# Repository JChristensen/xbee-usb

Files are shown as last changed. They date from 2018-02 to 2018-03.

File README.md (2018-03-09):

# XBee USB Dongle
https://github.com/JChristensen/xbee-usb  
README file  
Jack Christensen Feb-2018

## Overview
This dongle was mainly intended to connect an XBee semi-permanently to a Raspberry Pi, neatly without cables, for communication with an application program. Of course it can be used with any other computer as well. It's also useful for programming an XBee with [Digi's XCTU utility](https://www.digi.com/products/xbee-rf-solutions/xctu-software/xctu), or as a range extender in the mesh network by just plugging it into a 5V wall wart, phone charger, etc.

Via a solder jumper on the back of the board, the XBee's reset pin can be connected either to a pushbutton switch or to the CBUS3 pin on the FTDI FT231X chip. To use CBUS3 as a reset line, configure it as a GPIO pin using [the FTDI FT_PROG utility](http://www.ftdichip.com/Support/Utilities.htm#FT_PROG).

PC boards can be ordered [from OSH Park](https://www.oshpark.com/shared_projects/egIOkt1Z).  
A bill of materials is available [at Mouser Electronics](https://www.mouser.com/ProjectManager/ProjectDetail.aspx?AccessID=f236469f0d) and also in this repo.

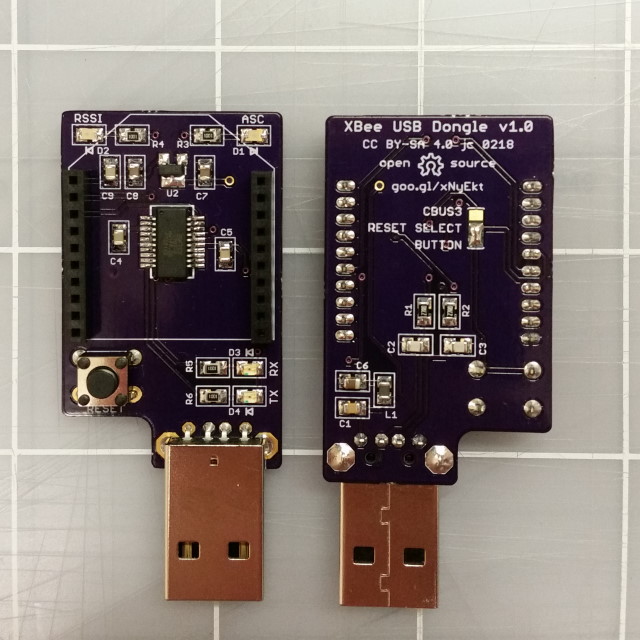
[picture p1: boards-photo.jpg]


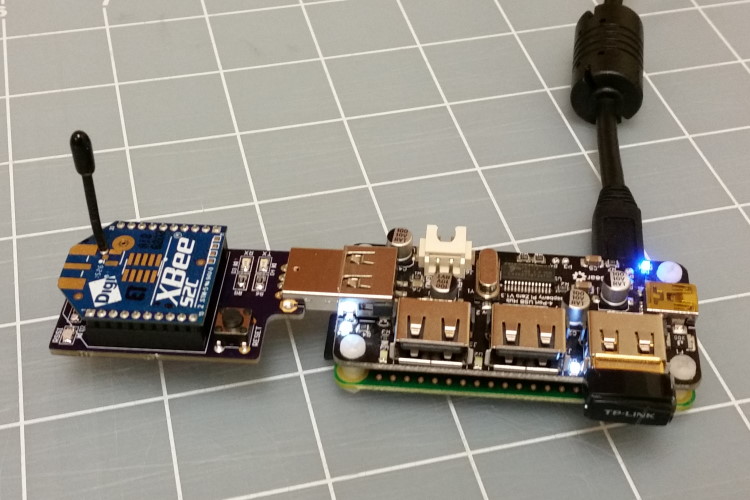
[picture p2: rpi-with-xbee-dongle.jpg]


**Raspberry Pi Zero with [Zero4U USB hub](https://www.adafruit.com/product/3298) and XBee USB Dongle.**

## CC BY-SA
"XBee USB Dongle" by Jack Christensen is licensed under [CC BY-SA 4.0](https://creativecommons.org/licenses/by-sa/4.0/).

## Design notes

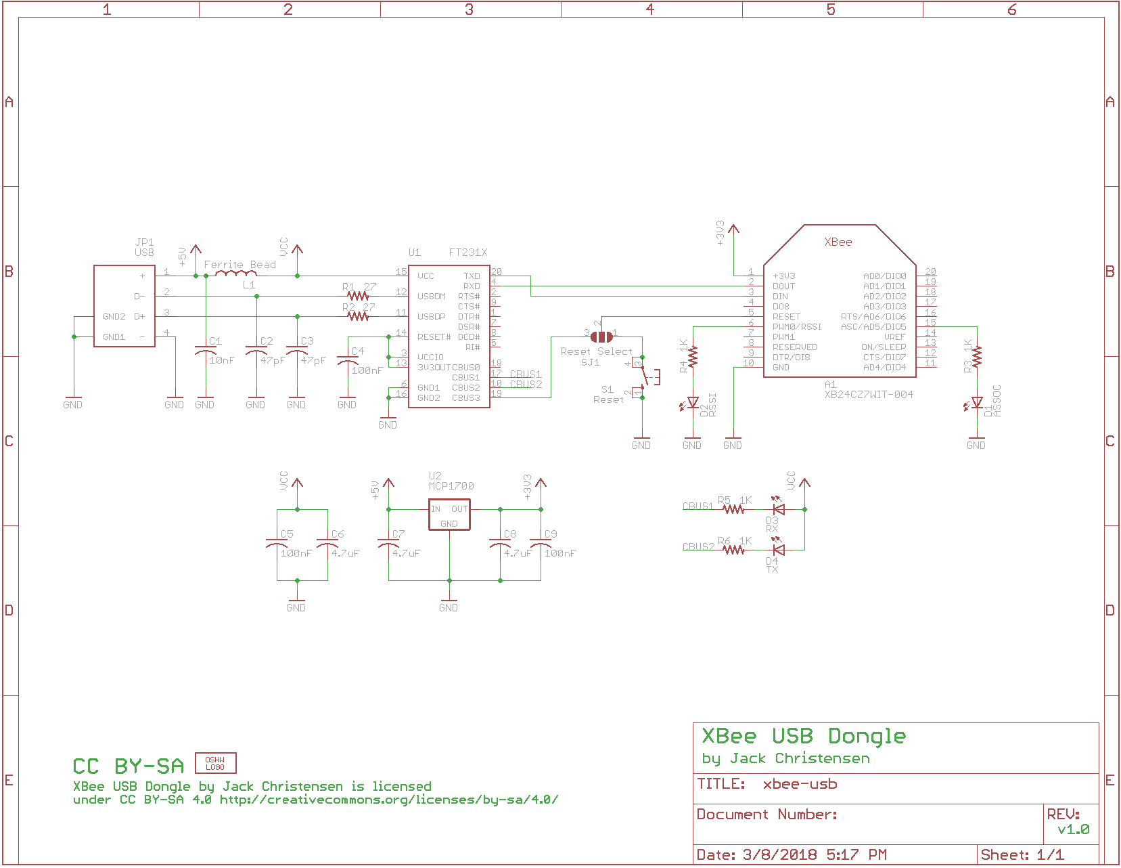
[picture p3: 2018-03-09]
schematic.png

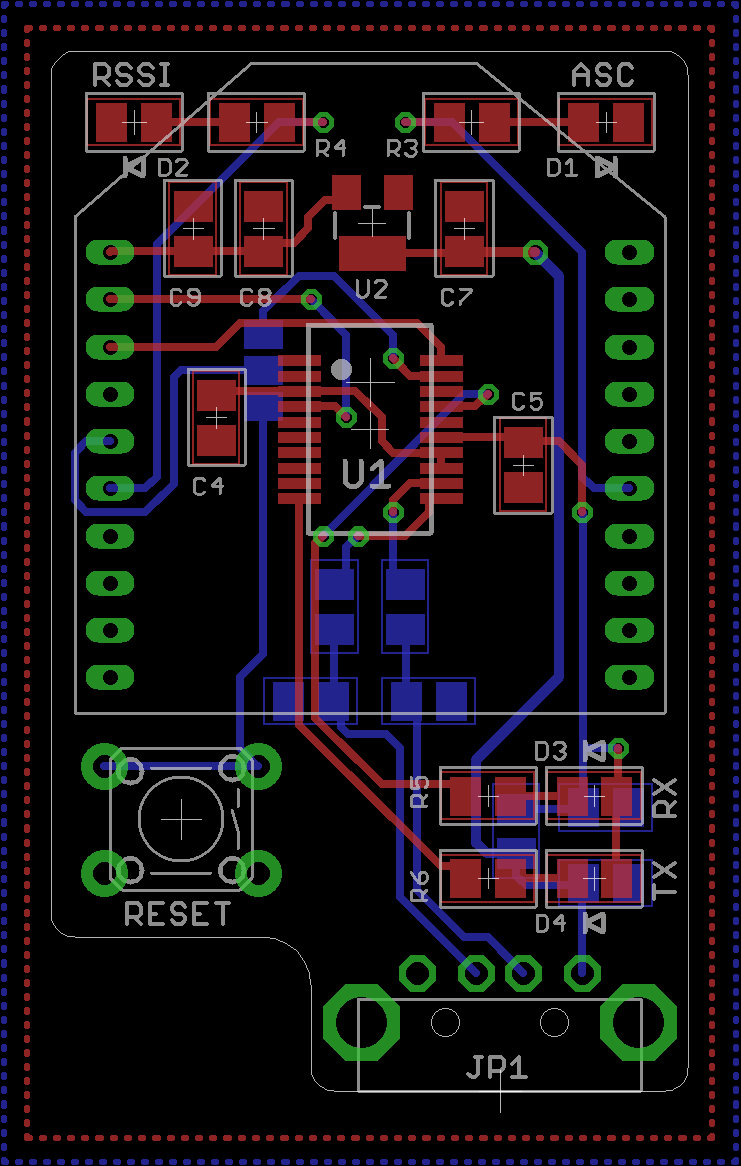
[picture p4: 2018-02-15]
board.png

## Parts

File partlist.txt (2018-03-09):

Partlist

Exported from xbee-usb.sch at 3/8/2018 5:17 PM

EAGLE Version 7.5.0 Copyright (c) 1988-2015 CadSoft

Assembly variant: 

Part     Value          Device             Package        Library  Sheet

A1       XB24CZ7WIT-004 ULINK_XBEEOVALPADS XBEE_OVAL_PADS _jc      1
C1       10nF           C-USM0805          M0805          _jc      1
C2       47pF           C-USM0805          M0805          _jc      1
C3       47pF           C-USM0805          M0805          _jc      1
C4       100nF          C-USM0805          M0805          _jc      1
C5       100nF          C-USM0805          M0805          _jc      1
C6       4.7uF          C-USM0805          M0805          _jc      1
C7       4.7uF          C-USM0805          M0805          _jc      1
C8       4.7uF          C-USM0805          M0805          _jc      1
C9       100nF          C-USM0805          M0805          _jc      1
D1       ASSOC          LEDD0805           D0805          _jc      1
D2       RSSI           LEDD0805A          D0805A         _jc      1
D3       RX             LEDD0805           D0805          _jc      1
D4       TX             LEDD0805A          D0805A         _jc      1
JP1      USB            UP2-AH-TH          UP2-AH-X-TH    _jc      1
L1       Ferrite Bead   INDUCTORM0805      M0805          _jc      1
R1       27             R-US_M0805         M0805          _jc      1
R2       27             R-US_M0805         M0805          _jc      1
R3       1K             R-US_M0805         M0805          _jc      1
R4       1K             R-US_M0805         M0805          _jc      1
R5       1K             R-US_M0805         M0805          _jc      1
R6       1K             R-US_M0805         M0805          _jc      1
S1       Reset          10-XXOCT           B3F-10XXOCT    _jc      1
SJ1      Reset Select   SJ2W               SJ_2           jumper   1
U1       FT231X         FT231XSSOP20-W     SSOP20-W       _jc      1
U2       MCP1700        MCP1700SOT23-W     SOT23-W        _jc      1

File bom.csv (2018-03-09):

XBee USB Dongle
Bill of Materials
Jack Christensen Mar-2018
https://github.com/JChristensen/xbee-usb
Part | Value | Order Qty. | Mouser # | Mfr. # | Manufacturer | Description
A1 | 2mm headers | 2 | 855-M22-7131042 | M22-7131042 | Harwin | Headers & Wire Housings 10 PIN SIL VERTICAL GOLD+TIN SOCKET
A1 | XB24CZ7WIT-004 (optional/or as desired) | 1 | 888-XB24CZ7WIT-004 | XB24CZ7WIT-004 | Digi International | Zigbee / 802.15.4 Modules XBee ZB S2C TH Wire Antenna
C1 | 10nF | 1 | 80-C0805C103J5R | C0805C103J5RACTU | KEMET | Multilayer Ceramic Capacitors MLCC - SMD/SMT 50volts 10000pF X7R 5%
C2,3 | 47pF | 2 | 603-CC805JRNPO9BN470 | CC0805JRNPO9BN470 | Yageo | Multilayer Ceramic Capacitors MLCC - SMD/SMT 47pF 50V NPO 5%
C4,5,9 | 100nF | 3 | 80-C0805C104K3R | C0805C104K3RACTU | KEMET | Multilayer Ceramic Capacitors MLCC - SMD/SMT 25volts 0.1uF X7R 10%
C6,7,8 | 4.7uF | 3 | 963-EMK212ABJ475KG-T | EMK212ABJ475KG-T | Taiyo Yuden | Multilayer Ceramic Capacitors MLCC - SMD/SMT 4.7uF 16V X5R 10% 0805
D1 | ASSOC (Green) | 1 | 710-150080GS75000 | 150080GS75000 | Wurth Electronics | Standard LEDs - SMD WL-SMCW SMDMono TpVw Waterclr 0805 Green
D2 | RSSI (Red) | 1 | 604-AP2012SRCPRV | AP2012SRCPRV | Kingbright | Standard LEDs - SMD RED WATER CLEAR 0805
D3,4 | TX/RX (Yellow) | 2 | 604-APT2012SYCK | APT2012SYCK | Kingbright | Standard LEDs - SMD YELLOW WATER CLEAR
JP1 | USB | 1 | 490-UP2-AH-1-TH | UP2-AH-1-TH | CUI Inc. | USB Connectors USB 2.0 type A plug 4 pin Horizontal TH
L1 | Ferrite Bead | 1 | 875-MI0805K400R-10 | MI0805K400R-10 | Laird | Ferrite Beads 40ohms 100MHz 1.5A Monolithic 0805 SMD
R1,2 | 27Ω | 2 | 603-RC0805FR-0727RL | RC0805FR-0727RL | Yageo | Thick Film Resistors - SMD 27 OHM 1%
R3-6 | 1K | 4 | 603-RC0805FR-071KL | RC0805FR-071KL | Yageo | Thick Film Resistors - SMD 1K OHM 1%
S1 | Reset | 1 | 653-B3F-1022 | B3F-1022 | Omron | Tactile Switches 6X6 Flat 5mm Btn Force 150g w/out Grd
U1 | FT231X | 1 | 895-FT231XS-R | FT231XS-R | FTDI | USB Interface IC USB to Full Serial UART IC SSOP-20
U2 | MCP1700 | 1 | 579-MCP1700T3302E/TT | MCP1700T-3302E/TT | Microchip | LDO Voltage Regulators 250mA Adj LDO 2%

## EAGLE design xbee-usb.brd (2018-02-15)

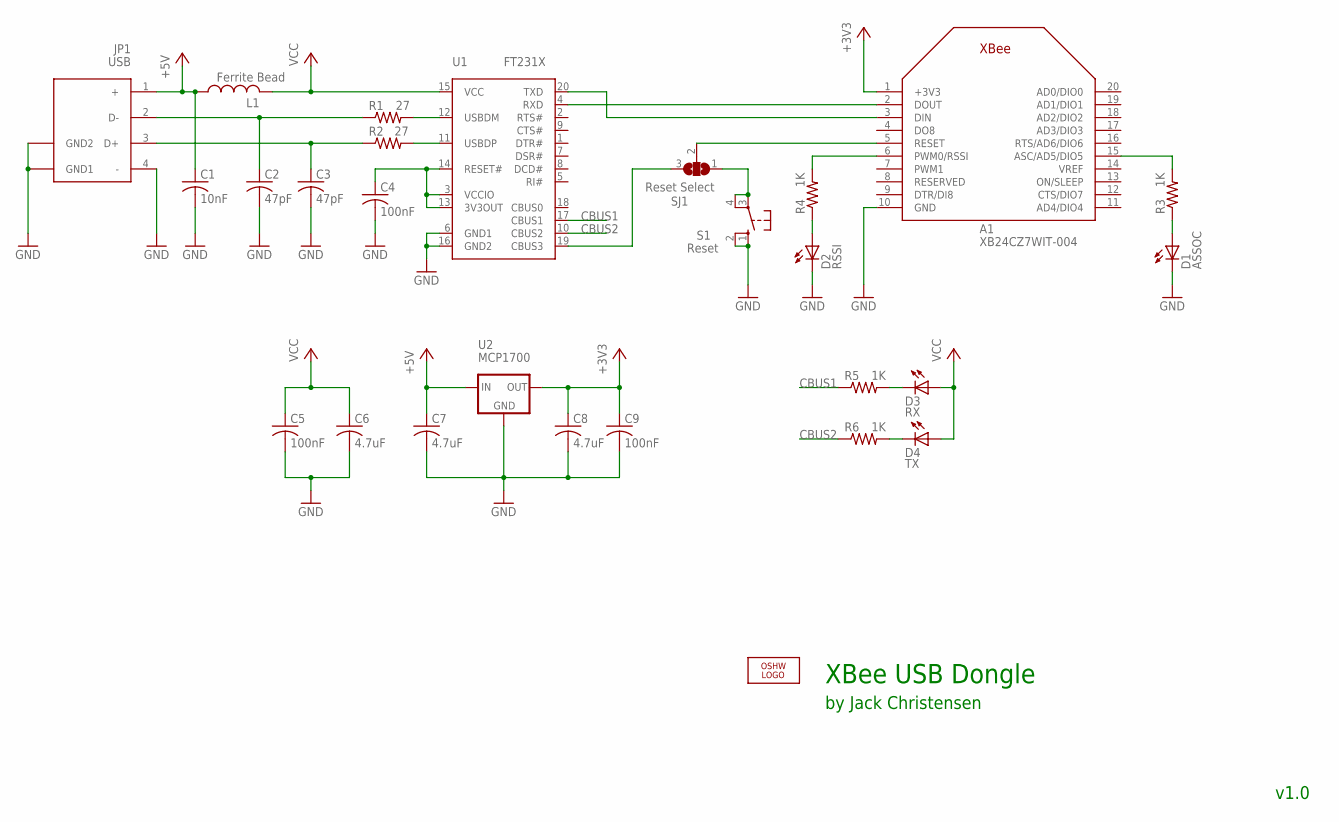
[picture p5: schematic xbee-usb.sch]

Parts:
A1: XB24CZ7WIT-004; XBEE_OVAL_PADS
C1: 10nF; M0805
C2, C3: 47pF; M0805
C4, C5, C9: 100nF; M0805
C6, C7, C8: 4.7uF; M0805
D1: ASSOC; D0805
D2: RSSI; D0805A
D3: RX; D0805
D4: TX; D0805A
JP1: USB; UP2-AH-X-TH
L1: Ferrite Bead; M0805
LOGO1: OSHW_LOGO_8MILX0100-NT; OSHW_8X100_NOTEXT
R1, R2: 27; M0805
R3, R4, R5, R6: 1K; M0805
S1: Reset; B3F-10XXOCT
SJ1: Reset Select; SJ_2
U1: FT231X; SSOP20-W
U2: MCP1700; SOT23-W

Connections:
+3V3: A1.1 (+3V3), C8.1, C9.1, U2.2 (OUT)
+5V: C1.1, C7.1, JP1.1 (+), L1.1, U2.3 (IN)
CBUS1: R5.1, U1.17 (CBUS1)
CBUS2: R6.1, U1.10 (CBUS2)
GND: A1.10 (GND), C1.2, C2.2, C3.2, C4.2, C5.2, C6.2, C7.2, C8.2, C9.2, D1.K (C), D2.K (C), JP1.4 (-), JP1.P$5 (GND1), JP1.P$6 (GND2), S1.1 (S), S1.2 (S1), U1.6 (GND1), U1.16 (GND2), U2.1 (GND)
unnamed: C2.1, JP1.2 (D-), R1.1
unnamed: C3.1, JP1.3 (D+), R2.1
unnamed: C4.1, U1.3 (VCCIO), U1.13 (3V3OUT), U1.14 (RESET#)
unnamed: R1.2, U1.12 (USBDM)
unnamed: R2.2, U1.11 (USBDP)
unnamed: A1.2 (DOUT), U1.4 (RXD)
unnamed: A1.3 (DIN), U1.20 (TXD)
unnamed: D3.K (C), R5.2
unnamed: A1.5 (RESET), SJ1.2
unnamed: D2.A, R4.1
unnamed: D1.A, R3.1
unnamed: A1.6 (PWM0/RSSI), R4.2
unnamed: A1.15 (ASC/AD5/DIO5), R3.2
unnamed: D4.K (C), R6.2
unnamed: S1.3, S1.4 (P1), SJ1.1
unnamed: SJ1.3, U1.19 (CBUS3)
VCC: C5.1, C6.1, D3.A, D4.A, L1.2, U1.15 (VCC)

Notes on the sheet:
XBee USB Dongle
by Jack Christensen
v1.0

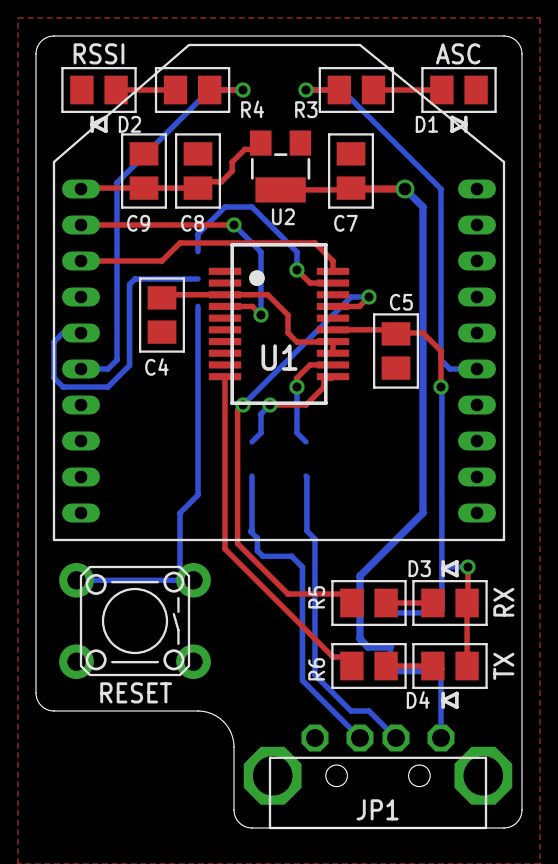
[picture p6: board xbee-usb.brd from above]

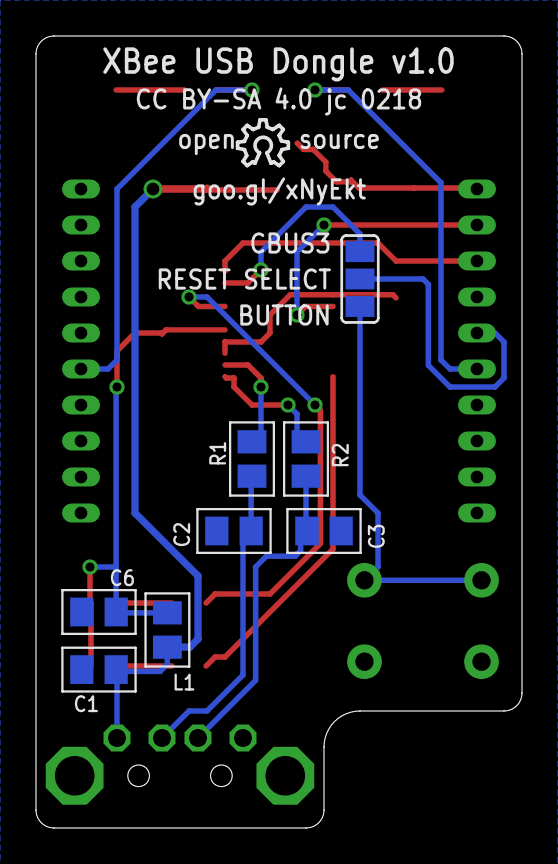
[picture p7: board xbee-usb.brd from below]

Board: 2 copper layers, 27.0 x 44.0 mm, 27 parts (9 on the bottom side), 22 nets.

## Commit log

2018-02-09 Initial commit.
    [xbee-usb.brd, xbee-usb.sch]
2018-02-15 As sent to fab.
    [xbee-usb.brd, xbee-usb.sch]
2018-03-09 Add photos, doc, BOM, etc.
    [bom.csv, bom.ods, xbee-usb.sch]

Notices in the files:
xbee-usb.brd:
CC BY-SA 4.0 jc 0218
